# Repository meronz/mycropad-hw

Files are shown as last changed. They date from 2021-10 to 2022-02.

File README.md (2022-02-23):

# Mycropad Hardware
Schematics and build files. Made with KiCAD and FreeCAD.

---
## Other Repos
- [Mycropad Firmware](https://github.com/meronz/mycropad-fw)
- [Mycropad Application](https://github.com/meronz/mycropad-app)

---
## Materials
These are the materials to buy if you want to build it. Buy links are here as an example, you can choose your own sources.

| Reference | Name |  Qty |  Value | Buy Link |
| :--- | :--- | :--- | :--- | :--- |
| C1 C2 C3 C4 C5 C6 C7 C8  | SMD Capacitor C1206 3216Metric | 8 | 10uF | https://it.aliexpress.com/item/4001345918046.html |
| D1 D2 D3 D4 D5 D6 D7 D8  | LEDS SK6812MINI-E PLCC4 3.5x3.5mm P1.75mm | 8 | NULL | https://www.aliexpress.com/item/1005002347411683.html |
| R1  | DIN0204 L3.6mm D1.6mm P7.62mm Horizontal | 1 | 200R | https://it.aliexpress.com/item/1005001489793822.html |
| R2  | DIN0204 L3.6mm D1.6mm P7.62mm Horizontal | 1 | 10k | https://it.aliexpress.com/item/1005001489793822.html |
| ROT1  | PEC12R-3225F-S0024 | 1 | NULL | https://www.digikey.it/it/products/detail/bourns-inc/PEC12R-3225F-S0024/4699267 |
| SW1 SW2 SW3 SW4 SW5 SW6 SW7 SW8  | KAILH MECHANICAL KEY SWITCHES - | 8 | NULL | https://www.adafruit.com/product/4952 |
| U1  | RASPBERRY PI PICO RP2040 BOARD | 1 | NULL | https://www.digikey.it/it/products/detail/raspberry-pi/SC0915/13624793 |
| U2  | SN74AHCT125N IC BUF NON-INVERT 5.5V 14DIP | 1 | NULL | https://www.digikey.it/it/products/detail/texas-instruments/SN74AHCT125N/375798 |
| NULL | CLEAR KEYCAPS FOR MX COMPATIBLE | 8 | NULL | https://www.adafruit.com/product/5068 |
| NULL | 30\*10MM Aluminium Alloy Potentiometer Knob Cap  | 1 | NULL | https://www.aliexpress.com/item/4001089749890.html |

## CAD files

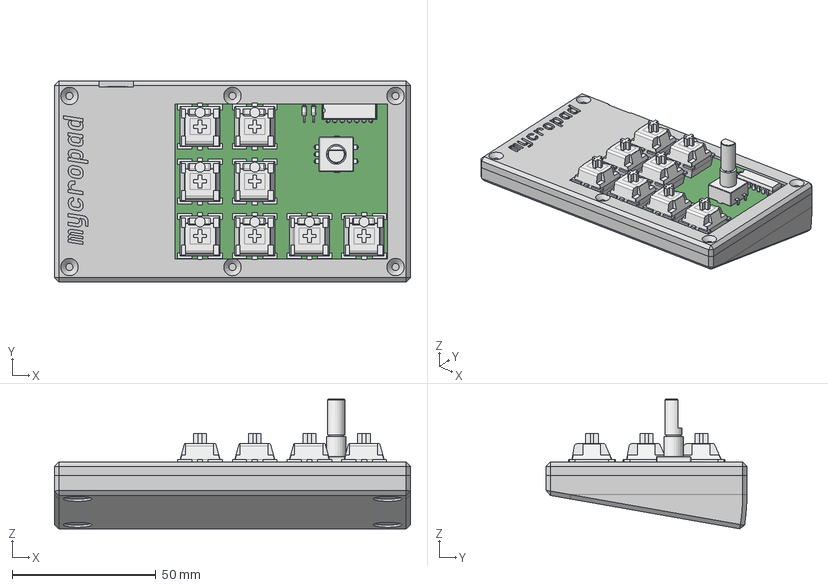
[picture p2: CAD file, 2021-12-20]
freecad/Mycropad.FCStd
124.0 x 70.0 x 45.1 mm
Enclosure
Cover

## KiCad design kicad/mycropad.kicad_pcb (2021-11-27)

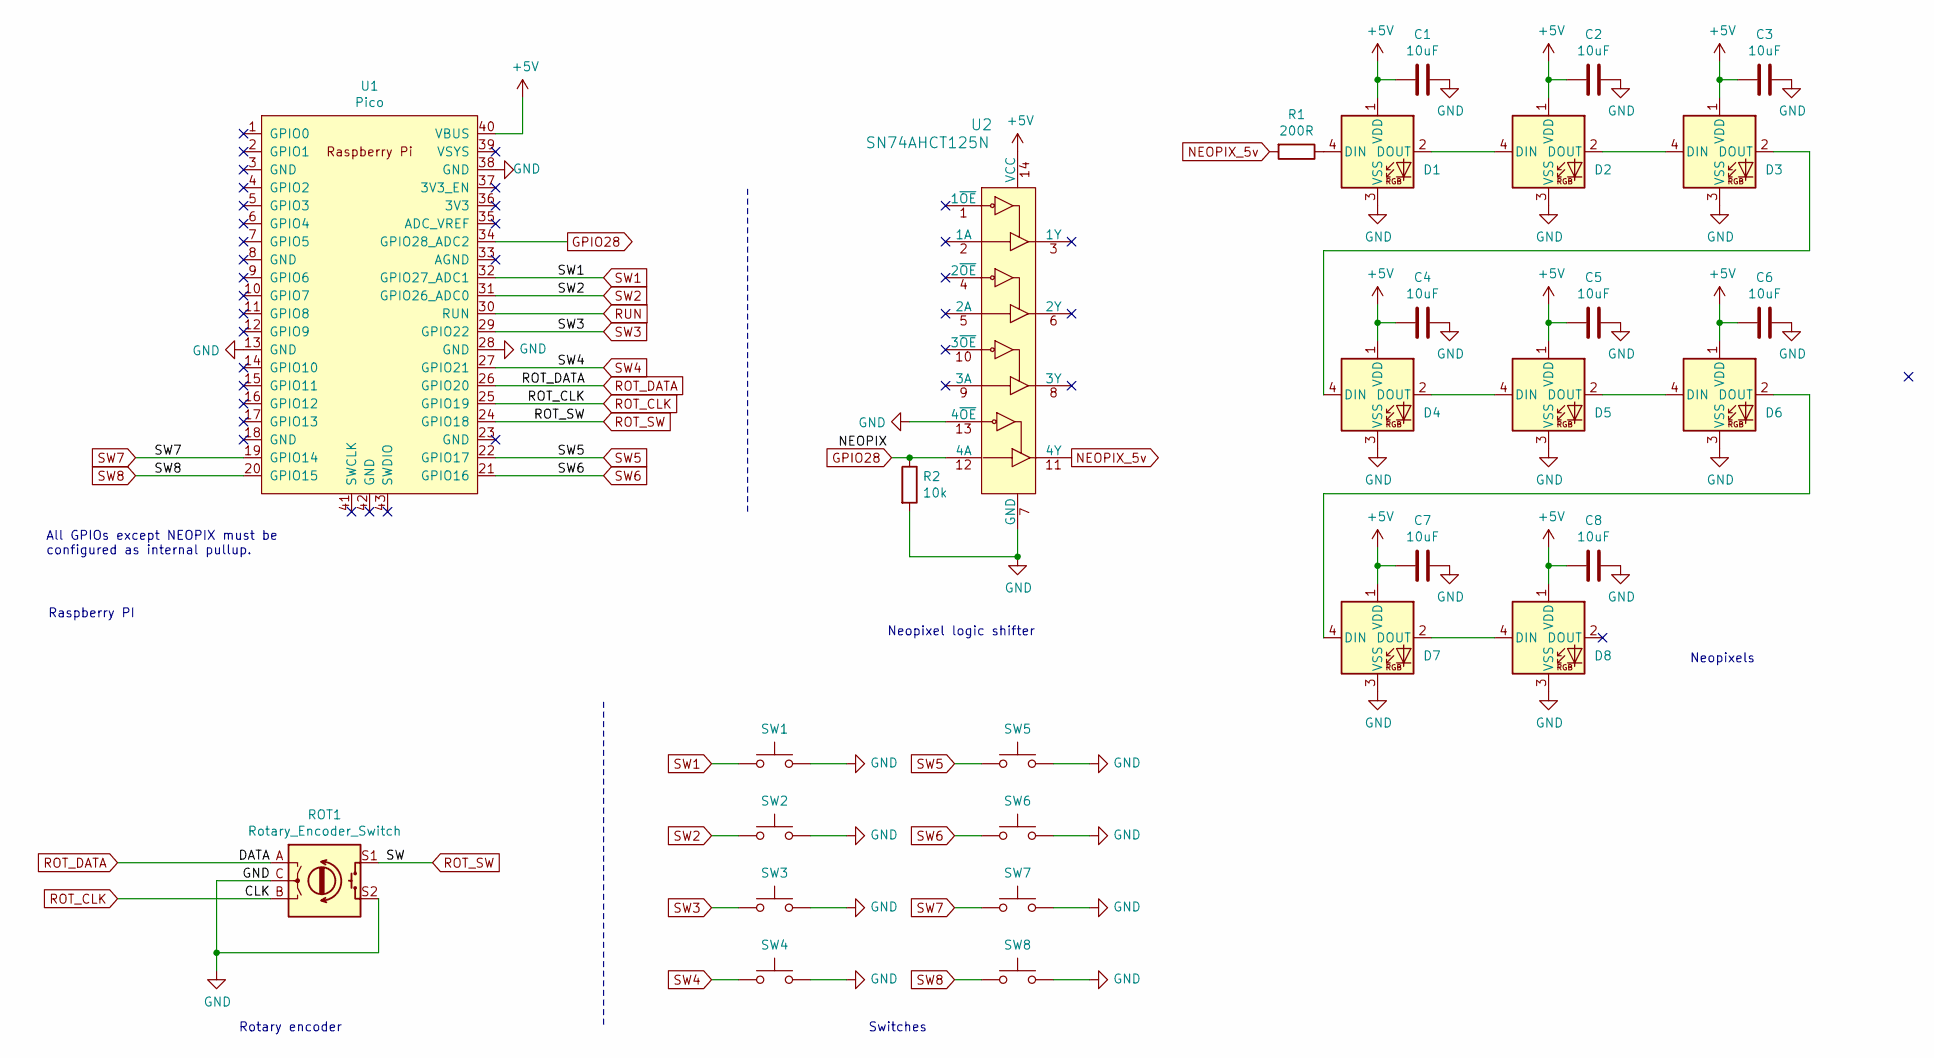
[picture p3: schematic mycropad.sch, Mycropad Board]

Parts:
C1, C2, C3, C4, C5, C6, C7, C8: 10uF; C_1206_3216Metric_Pad1.33x1.80mm_HandSolder; LCSC C13585
D1: SK6812MINI-E; LED_SK6812MINI-E_REV02_PLCC4_3.5x3.5mm_P1.75mm___V2; LCSC C13585
D2, D3, D4, D5, D6, D7, D8: SK6812MINI-E; LED_SK6812MINI-E_REV02_PLCC4_3.5x3.5mm_P1.75mm___V2
R1: 200R; R_Axial_DIN0204_L3.6mm_D1.6mm_P7.62mm_Horizontal
R2: 10k; R_Axial_DIN0204_L3.6mm_D1.6mm_P7.62mm_Horizontal
ROT1: Rotary_Encoder_Switch; RotaryEncoder_Alps_EC11E-Switch_Vertical_H20mm
SW1, SW2, SW3, SW4, SW5, SW6, SW7, SW8: SW_Push; SW_Cherry_MX_1.00u_PCB__Rotated
U1: Pico; RPi_Pico_SMD_TH
U2: SN74AHCT125N; DIP-14_W3mm; MPN SN74AHCT125N; Digi-Key_PN 296-4655-5-ND

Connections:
+5V: C1.2, C2.2, C3.2, C4.2, C5.2, C6.2, C7.2, C8.2, D1.1 (VDD), D2.1 (VDD), D3.1 (VDD), D4.1 (VDD), D5.1 (VDD), D6.1 (VDD), D7.1 (VDD), D8.1 (VDD), U1.40 (VBUS), U2.14 (VCC)
GND: C1.1, C2.1, C3.1, C4.1, C5.1, C6.1, C7.1, C8.1, D1.3 (VSS), D2.3 (VSS), D3.3 (VSS), D4.3 (VSS), D5.3 (VSS), D6.3 (VSS), D7.3 (VSS), D8.3 (VSS), R2.2, ROT1.C, ROT1.S2, SW1.2, SW2.2, SW3.2, SW4.2, SW5.2, SW6.2, SW7.2, SW8.2, U1.13 (GND), U1.28 (GND), U1.38 (GND), U2.7 (GND), U2.13 (4~OE)
GPIO28: R2.1, U1.34 (GPIO28_ADC2), U2.12 (4A)
NEOPIX_5v: R1.2, U2.11 (4Y)
unnamed: D1.2 (DOUT), D2.4 (DIN)
unnamed: D1.4 (DIN), R1.1
unnamed: D2.2 (DOUT), D3.4 (DIN)
unnamed: D3.2 (DOUT), D4.4 (DIN)
unnamed: D4.2 (DOUT), D5.4 (DIN)
unnamed: D5.2 (DOUT), D6.4 (DIN)
unnamed: D6.2 (DOUT), D7.4 (DIN)
unnamed: D7.2 (DOUT), D8.4 (DIN)
ROT_CLK: ROT1.B, U1.25 (GPIO19)
ROT_DATA: ROT1.A, U1.26 (GPIO20)
ROT_SW: ROT1.S1, U1.24 (GPIO18)
RUN: U1.30 (RUN)
SW1: SW1.1, U1.32 (GPIO27_ADC1)
SW2: SW2.1, U1.31 (GPIO26_ADC0)
SW3: SW3.1, U1.29 (GPIO22)
SW4: SW4.1, U1.27 (GPIO21)
SW5: SW5.1, U1.22 (GPIO17)
SW6: SW6.1, U1.21 (GPIO16)
SW7: SW7.1, U1.19 (GPIO14)
SW8: SW8.1, U1.20 (GPIO15)

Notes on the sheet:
Rotary encoder
Switches
Neopixel logic shifter
Neopixels
All GPIOs except NEOPIX must be configured as internal pullup.
Raspberry PI

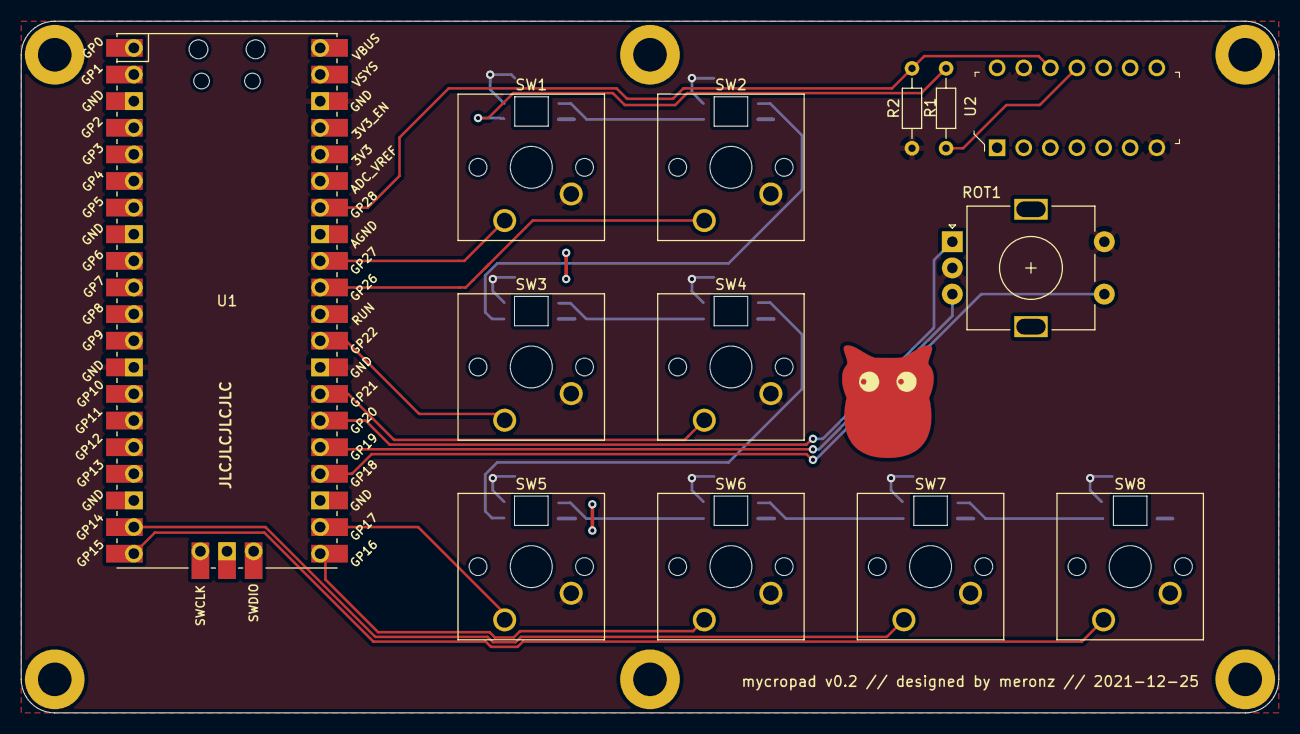
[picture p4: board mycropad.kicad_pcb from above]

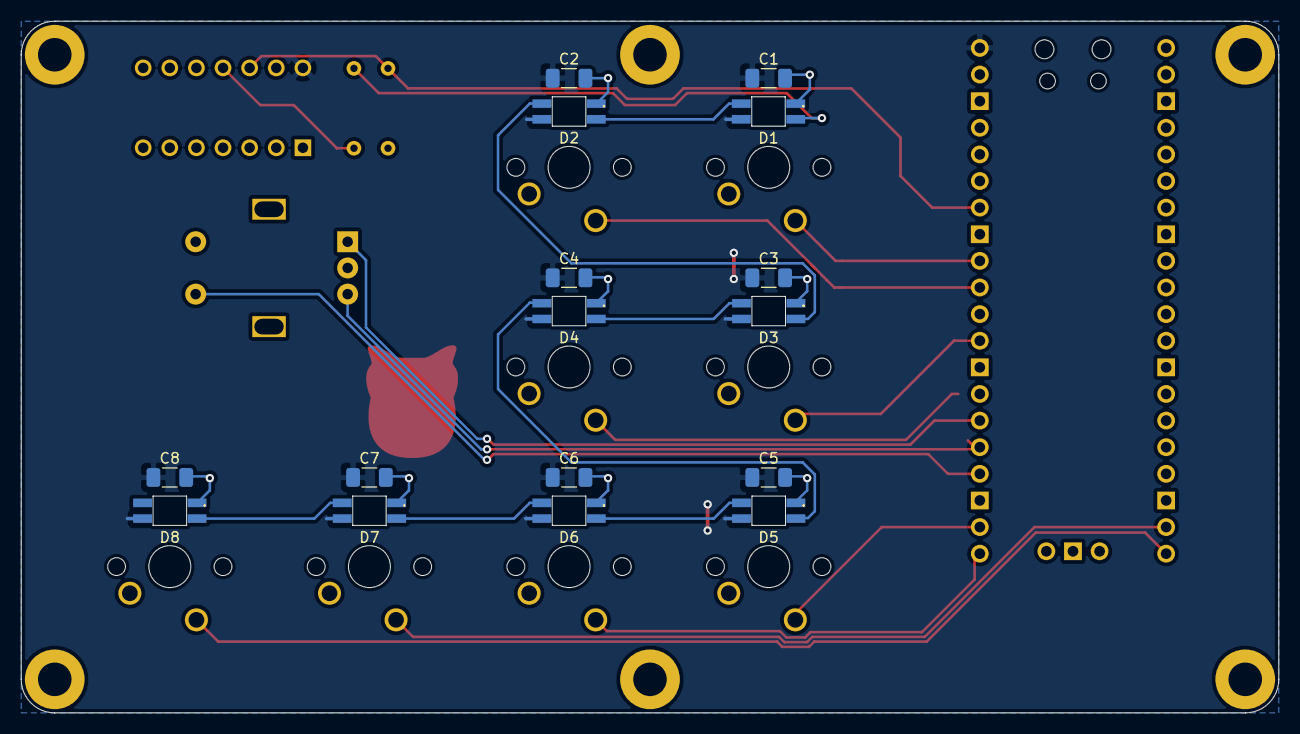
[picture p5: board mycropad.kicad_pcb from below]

Board: 2 copper layers, 120.0 x 66.0 mm, 36 parts (16 on the bottom side), 23 nets.

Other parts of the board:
M1, M2, M3, M4, M5, M6: MountingHole_3.2mm_M3_ISO7380_Pad
Ref**: Val**; owl_drawing

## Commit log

2021-10-07 WIP, first mockups
    [mycropad.kicad_pcb, mycropad.sch]
2021-10-07 Proper edges given
    [mycropad.kicad_pcb]
2021-10-07 Even better
    [mycropad.kicad_pcb, mycropad.sch]
2021-10-08 Added some 3d models
    [mycropad.kicad_pcb]
2021-10-09 Updated footprints
    [mycropad.kicad_pcb, mycropad.sch]
2021-10-09 Moved around some things
    [mycropad.kicad_pcb, mycropad.sch]
2021-10-30 Removed useless resistors, PCB design fixes.
    [mycropad.kicad_pcb, mycropad.sch]
2021-10-30 Restored original RPi SMD footprint
    [mycropad.kicad_pcb, mycropad.sch]
2021-10-30 Reinserted pcb mounting holes
    [mycropad.kicad_pcb]
2021-10-30 New reverse mount led. Let's hope it works...
    [mycropad.kicad_pcb, mycropad.sch]
2021-11-01 Updated footprints for SK6812 MINI-E.
    [mycropad.kicad_pcb, mycropad.sch]
2021-11-01 Adding FreeCAD project
    [Mycropad.FCStd]
2021-11-01 Completed top cover
    [Mycropad.FCStd]
2021-11-08 Added chamfer on the bottom to avoid elephant foot
    [Mycropad.FCStd]
2021-11-11 Enclosure fixes after the first printing test
    [Mycropad.FCStd]
2021-11-11 mycropad v0.2 started.
    [mycropad.kicad_pcb, mycropad.sch]
2021-11-11 mycropad v0.2 enclosure adjustments
    [Mycropad.FCStd]
2021-11-17 Changed board layout, r1 & r2 footprints, added reset button
    [mycropad.kicad_pcb, mycropad.sch]
2021-11-19 v0.2 enclosure, with new cover and inclined base
    [Mycropad.FCStd, mycropad.kicad_pcb]
2021-11-19 New pcb holes layout
    [mycropad.kicad_pcb]
2021-11-27 Changed holes position
    [Mycropad.FCStd, mycropad.kicad_pcb, mycropad.sch]
2021-11-27 Added owl art to pcb.
    [mycropad.kicad_pcb]
2021-11-27 Adapted holes to new pcb v0.2
    [Mycropad.FCStd]
2021-12-20 Edits before final print
    [Mycropad.FCStd]
2022-02-23 Added materials.
